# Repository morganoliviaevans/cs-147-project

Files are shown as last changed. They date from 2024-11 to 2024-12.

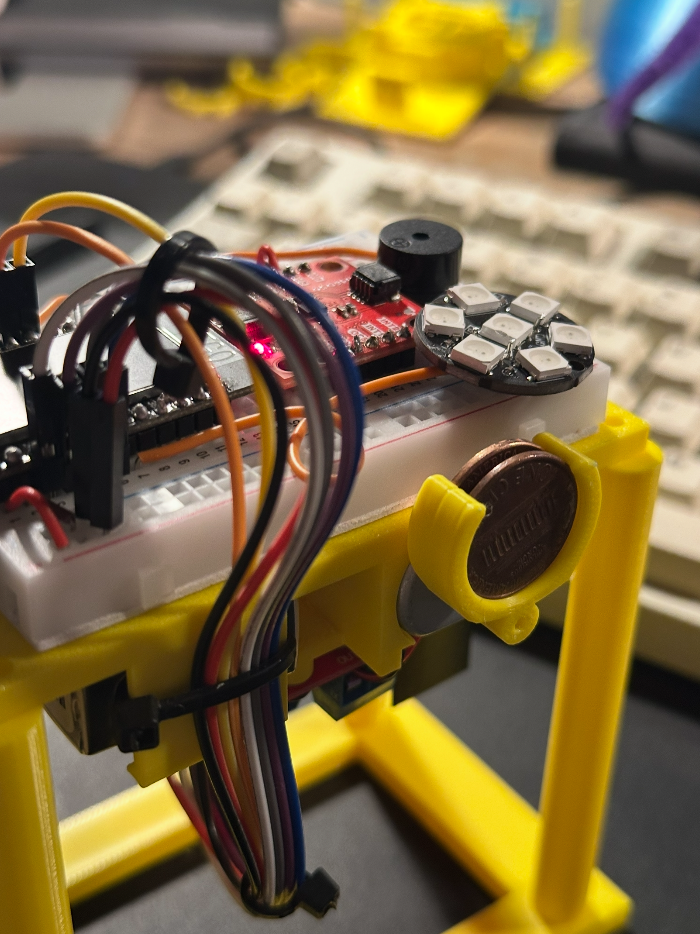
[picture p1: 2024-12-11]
images/hardware-housing1.png

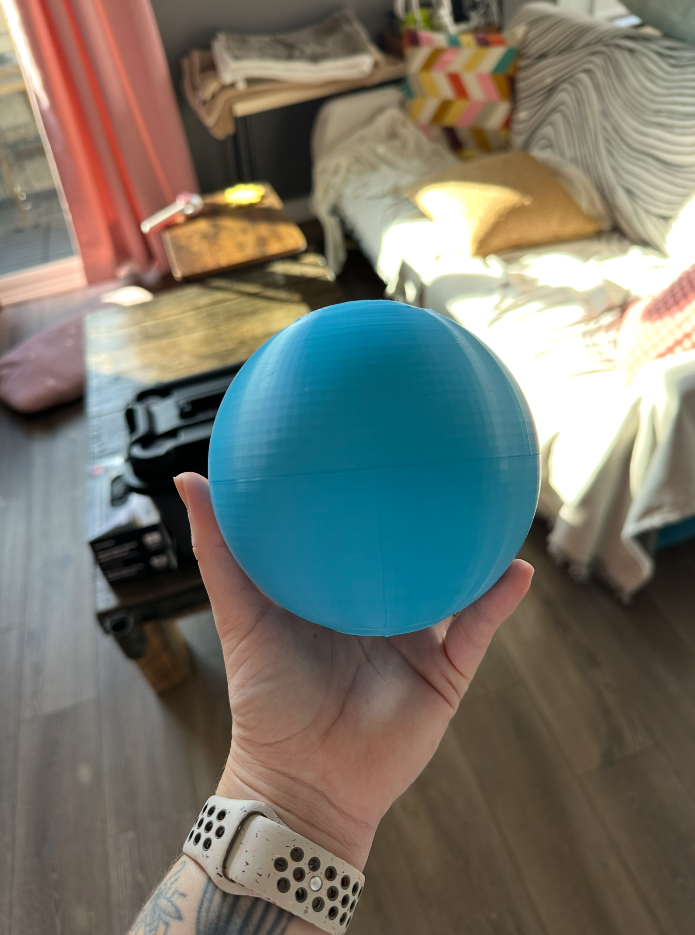
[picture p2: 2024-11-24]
images/design-prototype.png

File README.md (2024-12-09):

# Smarter Playtime: Developing a Motion-Based Motorized Cat Toy for Active Engagement

## Project Overview

This repository contains the files for **"Smarter Playtime"**, a project developed as part of **CS 147: Internet of Things (IoT) Software and Systems**. The project aims to provide active engagement for cats through a motorized toy that incorporates motion detection, customizable features, and automated play patterns to keep cats entertained.

## Team Information

- **Team Name**: Kitty Kinetics
- **Team Members**:
  - **Morgan Newton** – monewton@uci.edu
  - **Carm Hermosilla** – cyhermos@uci.edu

## Motivation

Many cat toys available today fail to keep cats consistently entertained, leading to a lack of exercise and stimulation. This can cause behavioral and health problems for pets, creating stress for both cats and their owners. Our project aims to solve this by providing a customizable, automated solution to ensure cats stay active and engaged.

## Project Goals

The project focuses on developing a motorized toy with interchangeable attachments (feathers, bells, ribbons, etc.), automated movement triggered by motion detection, visual stimulation using LEDs, and bird chirping via a buzzer. Power is supplied via rechargeable LIPO battery for convenience and long-term usability.

## Repository Structure

- **/src**: Source code for the project.
- **/docs**: Documentation, design, and architecture.
- **/images**: Photos and diagrams of the prototype and development process.

## Hardware Components

- LilyGo ESP32 microcontroller
- LED Ring
- Accelerometer
- Motor and Motor Driver
- 3D-printed spherical housing
- LIPO battery
- Toy attachments (feathers, wiggly worms, etc.)
- Buzzer

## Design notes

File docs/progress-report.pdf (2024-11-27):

COMPSCI 147: IOT SW AND SYSTEMS | PROJECT PROGRESS REPORT

## Project Title

(Try to choose a catchy title. Max 20 words).

Smarter Playtime: Developing a Motion-Based Motorized Cat Toy for Active Engagement

## Student and Team Information

Team Name: Kitty Kinetics Team # on Canvas: 2

Team member 1 (Team Lead): Newton, Morgan: 40885576: monewton@uci.edu | Newton, Morgan – 40885576

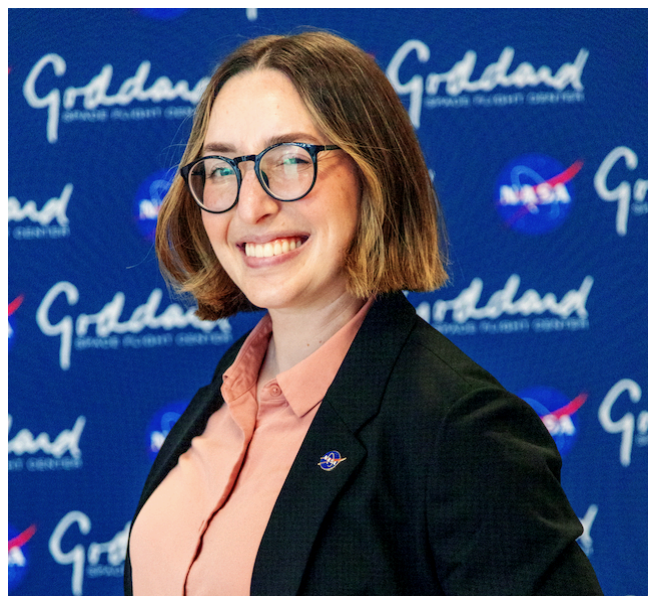
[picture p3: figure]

Team member 2: Hermosilla, Carm: 76038461: cyhermos@uci.edu | Hermosilla, Carm – 76038461

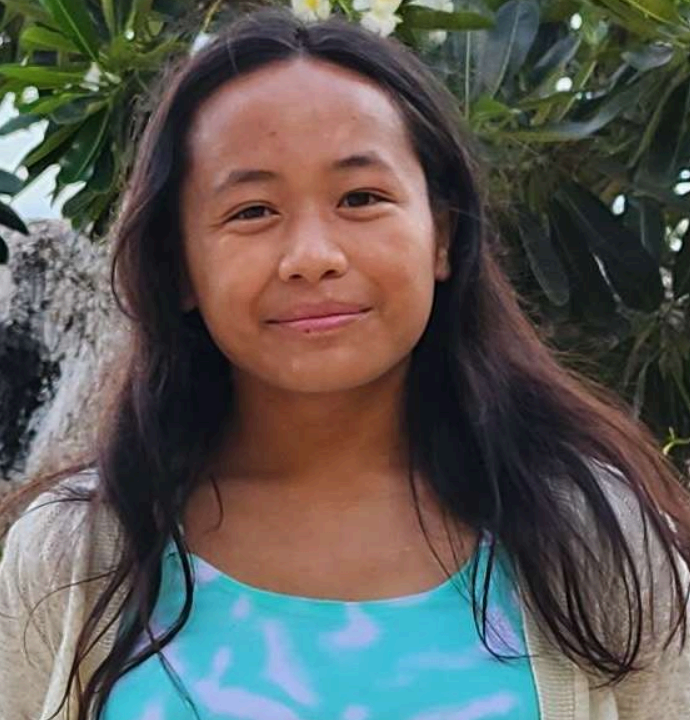
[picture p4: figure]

v.01-26032021 | Page 1

## Updated Project Approach (10 points)

(Describe how you plan to articulate and design a solution, architecture you are finally using and communication protocol (Wi-Fi, BLE, ...). Include all project milestones as well. Max 300 words).

Our project uses a motion, sound and light approach to engage cats, with an architecture based on the LilyGo ESP32 microcontroller. We decided to use an accelerometer to detect movement along the x, y, or z axes, triggering the toy when a cat interacts with it. After experimenting with proximity sensing, we opted to omit it because it is impractical for a spherical design. The toy is housed in a modified hollow sphere, allowing embedded LEDs and attachments like feathers or bells. The .stl file was downloaded for free from Thingiverse and manually adjusted per our device specifications. Power will be supplied via an external USB power bank for simplicity and ease of replacement. We realized that a shutdown mode is unnecessary as the device powers off naturally when the battery depletes. We want the cats to enjoy playing with the device for as long as possible.

## Updated Hardware Components (5 pts)

(The final list and quantity of the required components for the project)

Component | Type | Quanti ty | Ordered?
Microcontroller | LilyGo ESP32 | 1
LEDs | LEDs (https://www.amazon.com/gp/product/B0C7C9HP9R/ref=ppx_yo_dt_b_asin_title_o00_s01?ie=UTF8&th=1) | 1
Resistors | Resistors | 1-4
Accelerometer | Accelerometer (https://www.sparkfun.com/products/18020) | 1
Spherical housing | Thingiverse (https://www.thingiverse.com/thing:5828088) | 1
Motor | Motor (https://www.amazon.com/gp/product/B09FPXF1QK/ref=ppx_yo_dt_b_asin_title_o00_s00?ie=UTF8&th=1) Motor tutorial (https://www.tutorialspoint.com/arduino/arduino_dc_motor.htm) | 1
Motor driver | Motor Driver (https://www.amazon.com/gp/product/B0CR6BX5QL/ref=ppx_yo_dt_b_asin_title_o00_s01?ie=UTF8&psc=1) | 1
USB Power supply | *Need to find a small rechargeable power bank* | 1
Motor power supply | *Potentially going to use a Lipo battery* | 1
Buzzer | Buzzer/Speaker | 1
Attachments | Feathers, bells, wiggly worms | 5

## Completed Project Tasks (15 pts)

(Describe the main tasks that have been assigned and already completed. Max 250 words)

Task Completed | Team Member
Designed and printed a hollow sphere prototype from Thingiverse and tested it with the cats. They seemed to like it! | Morgan
Adjusted the housing file to add perforations for the LED lights and an embedded hook for attachments. | Morgan
Implemented sensor logic for initializations, LED flashing, bird chirps, and motion detection using an accelerometer. | Morgan
Ordered the rest of our parts: LED, motor, motor driver, device attachments | Morgan

## Challenges and Roadblocks (10 pts)

(Describe the challenges that you have faced or are facing so far and how you plan to solve them. Max 300 words)

Balancing the scope and timeline of the project has been a challenge, requiring us to simplify certain features, such as omitting battery life tracking, which was deemed unnecessary. I think we got a bit too ambitious! We also faced hardware compatibility issues, as initial microcontroller libraries caused delays, but these were resolved by switching to more suitable options. Fine-tuning the accelerometer’s logic has been another focus, ensuring it responds accurately to motion while avoiding false triggers. To streamline power management, we are opting for an external USB power bank, eliminating the need for a shutdown mode, which significantly simplifies the design. Additionally, proximity sensing was excluded from the project due to the spherical housing design, which made it impractical to direct sensors effectively. For example, the sensor might be pointed down at the ground, which would pose issues with reading. Instead, we will rely on accelerometer-based motion detection to activate the toy. Additionally, programming each peripheral to run concurrently proved to be much more difficult than originally planned.

## Pending Tasks (10 pts)

(Describe the main tasks that you still need to complete. Max 250 words)

Task | Team Member
Adding AWS data analytics tracking for play time | Morgan
Analyzing and summarizing data analytics | Carm
Select and test an external USB power solution | Morgan
Hardware Build | Carm
Testing the device | Morgan
Logic adjustments | Morgan
Demo Video | Carm + Morgan
Final Report | Carm + Morgan

## Weak Points and Future Work (15 pts)

(Mention at least two points of your project that have room for improvement. These points can be additions to the existing project setup (components) or improvement of the current implementation. Max 200 words)

For future iterations, integrating a power source that allows battery tracking would enhance usability by providing real-time feedback on battery levels. This would be helpful in analyzing battery life to compare different, better options, if necessary. Additionally, modifying the spherical housing to include a weighted base could improve stability and create opportunities for incorporating proximity sensing functionality, which was not feasible in the current design. Another area for improvement could involve refining the accelerometer’s sensitivity and responsiveness, enabling more precise motion detection. Adding customizable play patterns, such as programmed light and sound sequences, could further enhance the toy’s engagement factor. Adjusting peripheral timing was also fairly difficult. Future implementations would hopefully focus on creating logic to allow parallel peripheral execution. Lastly, if we hypothetically were interested in bringing the device to market, exploring durable materials for the housing could extend the product’s lifespan, as well as sourcing smaller hardware components.

## Demo Video (15 pts)

Please include a link to a demo video showing the initial setup, the components and functionality of your IoT system (5 min max). If you cannot provide a video yet, please explain the reasons. Max 150 words).

Our demo video showcases Charlie (Morgan’s cat) playing with the 3D-printed ball prototype, made of PLA. The second clip demonstrates the sleep state to play state transition. If the toy is moved, the play state is activated. The third video showcases the serial monitor output, displaying the toy’s state, its position via x and y coordinates, and magnitude to elucidate how much the toy has moved. The play state will move each motor randomly, flash the led, and chirping noises. If the cat is not interested momentarily, the hunting state is activated which turns on the led and chirping noises. If the cat is completely uninterested, the device shifts to a sleep state to consume less battery. This output will be sent to the AWS database to monitor the current session’s play duration and frequency between interactions. State timing changes have small delays for demonstration purposes, but will be readjusted after testing.

Watch Demo Video Here (https://drive.google.com/file/d/1DOTv-FsJgOIQEgGuwi69TlJ3ngiTCjjo/view?usp=sharing)

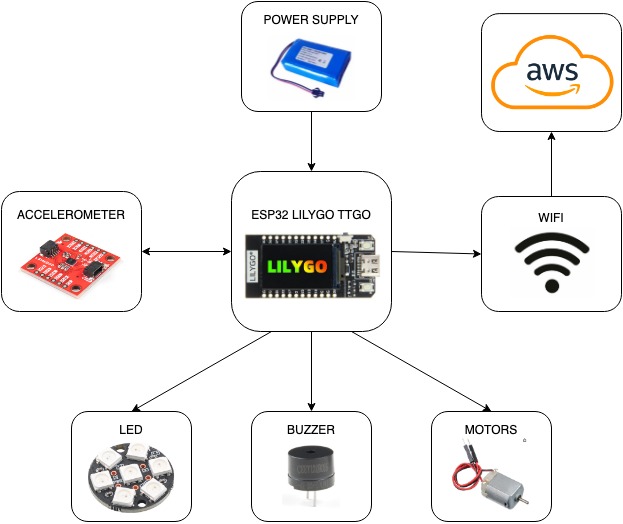
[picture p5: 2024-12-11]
images/architecture-diagram.jpg

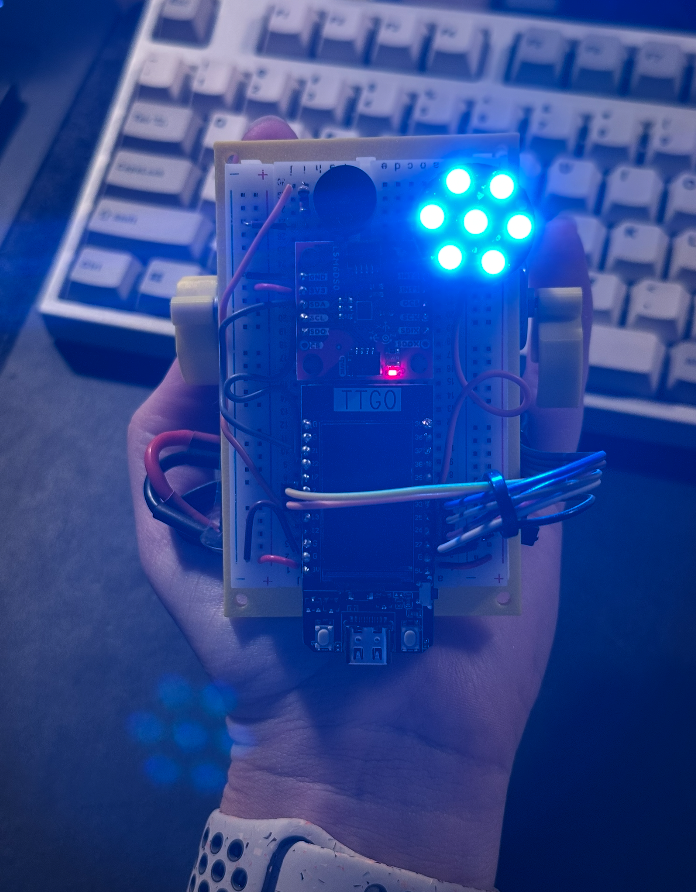
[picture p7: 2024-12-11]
images/hardware-housing6.png

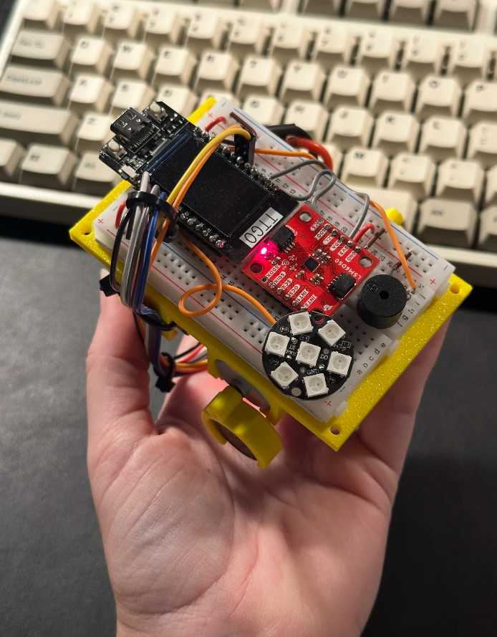
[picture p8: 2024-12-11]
images/hardware-housing2.png

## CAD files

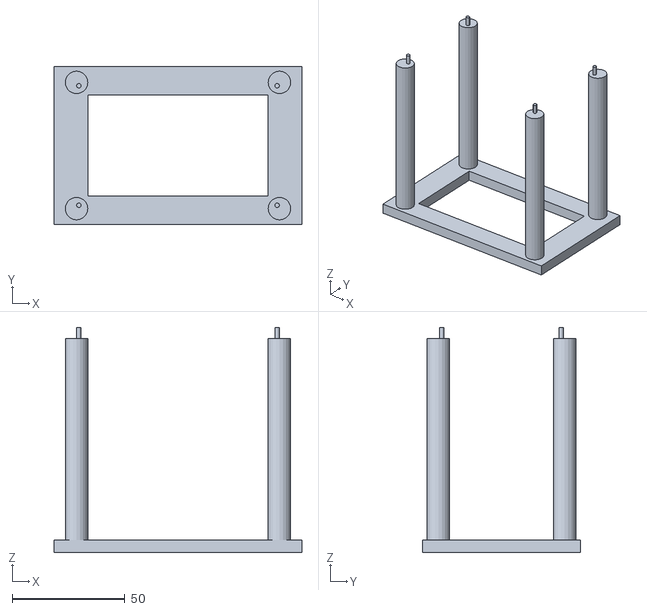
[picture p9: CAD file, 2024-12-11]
3d-housing/final/final-device-plate-stand.stl
110.0 x 70.0 x 100.0

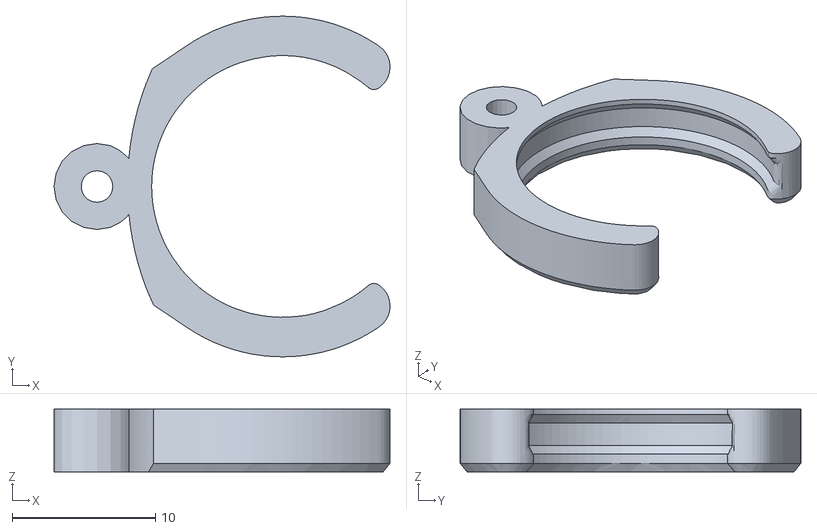
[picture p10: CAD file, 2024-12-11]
3d-housing/penny-weight-single.stl
23.4 x 23.8 x 4.39

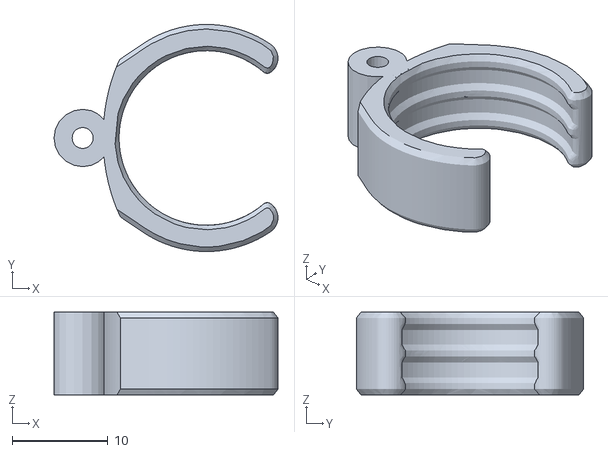
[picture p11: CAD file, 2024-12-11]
3d-housing/final/final-penny-weight-double.stl
23.4 x 23.8 x 8.67

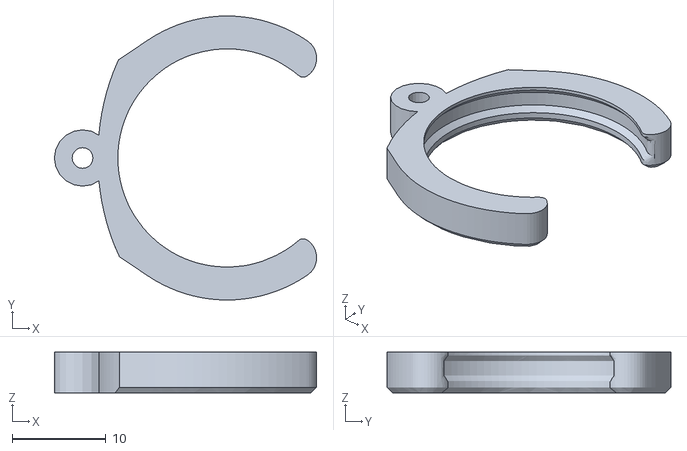
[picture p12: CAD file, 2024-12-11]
3d-housing/quarter-weight-single.stl
27.9 x 30.2 x 4.34

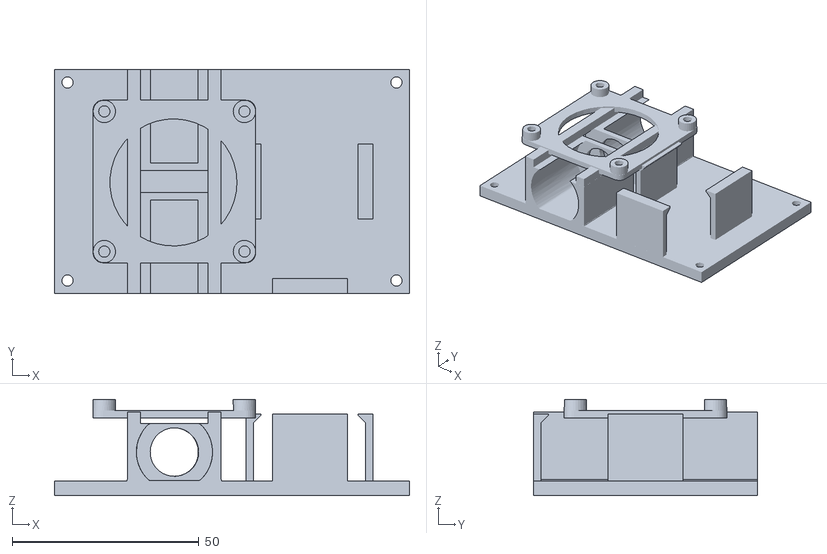
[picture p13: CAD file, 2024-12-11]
3d-housing/final/final-motor-hardware-plate.stl
95.0 x 60.0 x 25.8

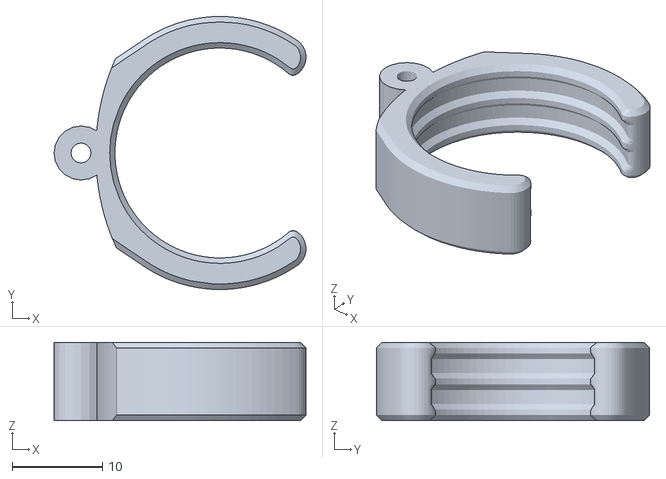
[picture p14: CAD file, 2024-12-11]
3d-housing/quarter-weight-double.stl
27.9 x 30.3 x 8.67

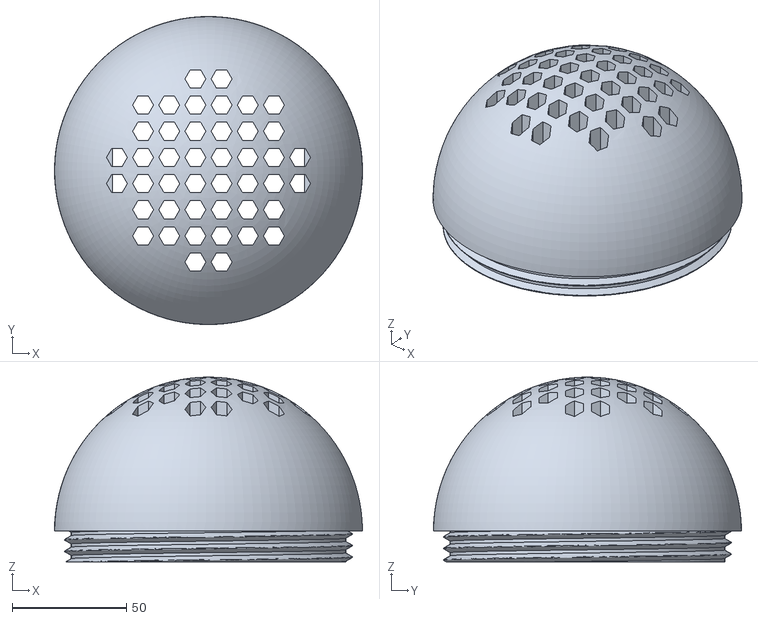
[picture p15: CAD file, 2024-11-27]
3d-housing/final/final-sphere-male-perforated.stl
135.0 x 135.0 x 81.0

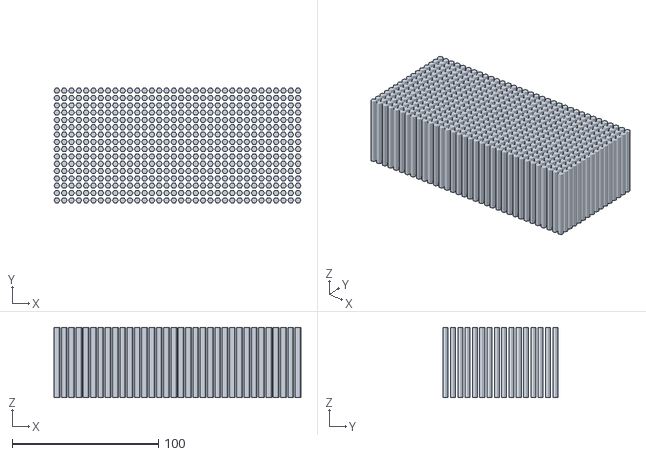
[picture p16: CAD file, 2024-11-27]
3d-housing/perforation-raw.stl
169.0 x 78.5 x 48.0

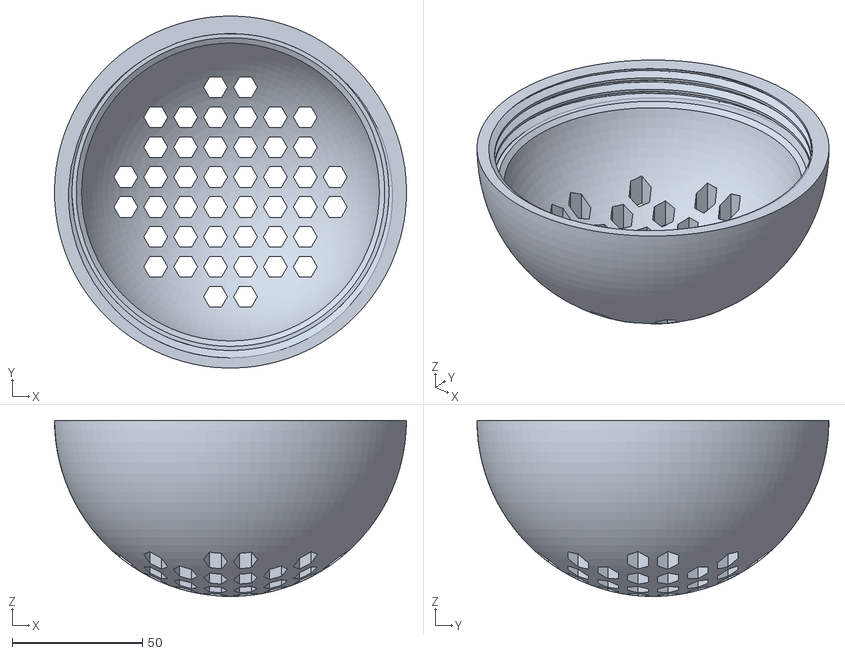
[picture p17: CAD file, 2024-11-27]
3d-housing/final/final-sphere-female-perforated.stl
135.0 x 135.0 x 67.5

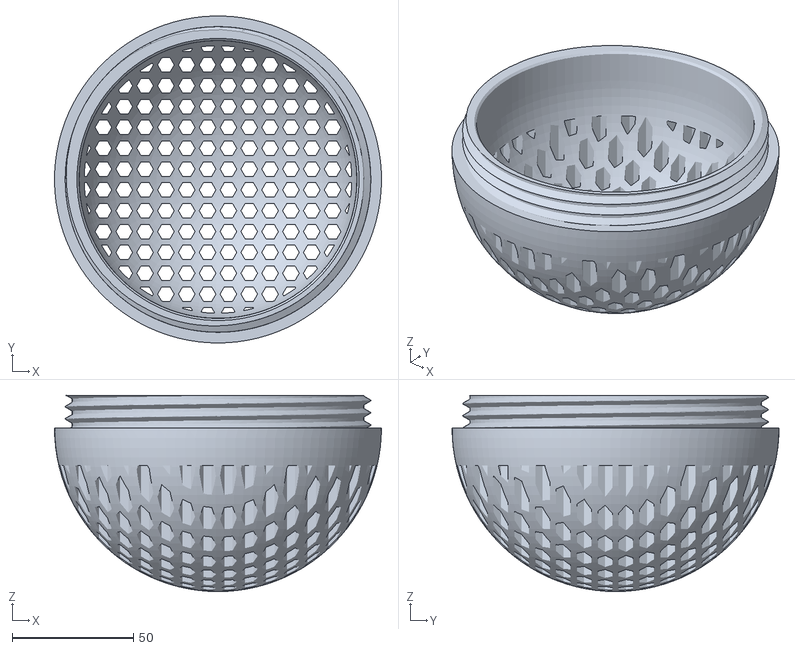
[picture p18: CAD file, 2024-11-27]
3d-housing/male-sphere-perforated.stl
135.0 x 135.0 x 81.0

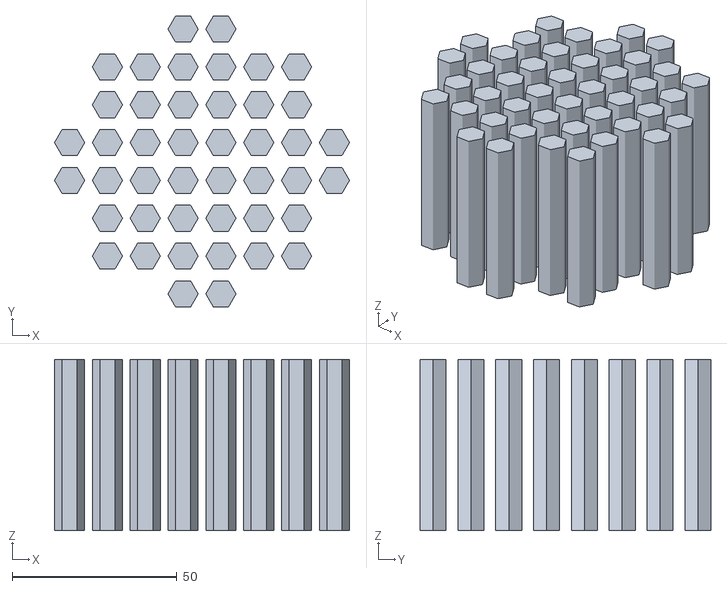
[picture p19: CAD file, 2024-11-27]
3d-housing/perforation-scaled.stl
89.5 x 88.2 x 52.0

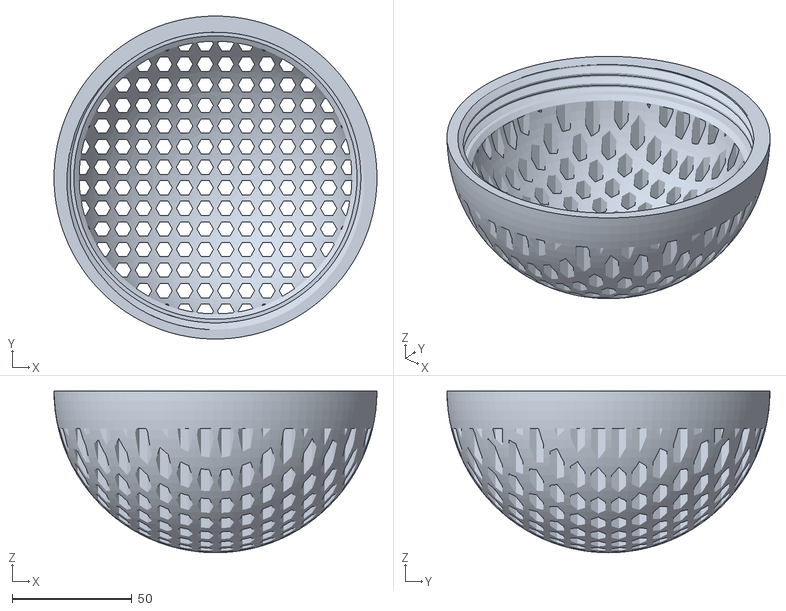
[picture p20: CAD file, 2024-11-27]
3d-housing/female-sphere-perforated.stl
135.0 x 135.0 x 67.5

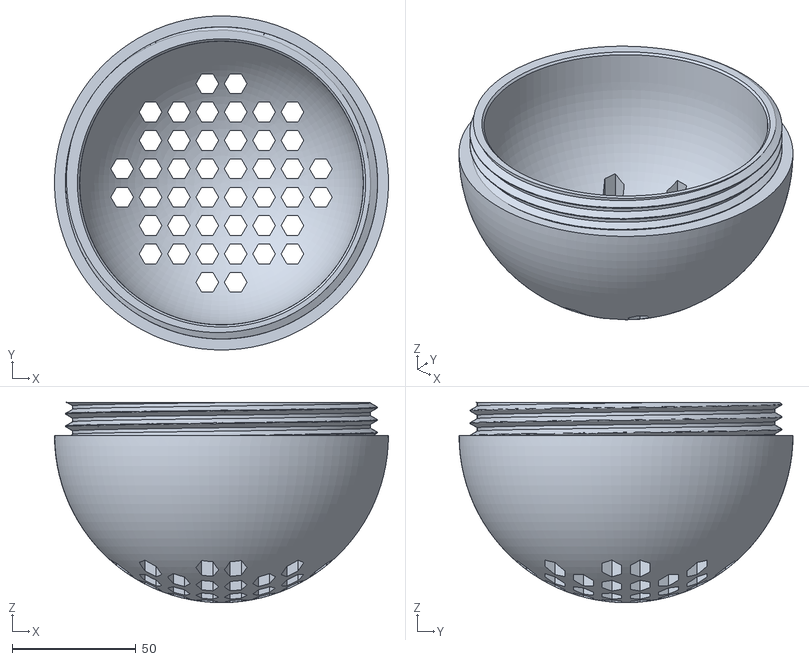
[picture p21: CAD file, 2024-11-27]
3d-housing/male-perforated-no-mount.stl
135.0 x 135.0 x 81.0

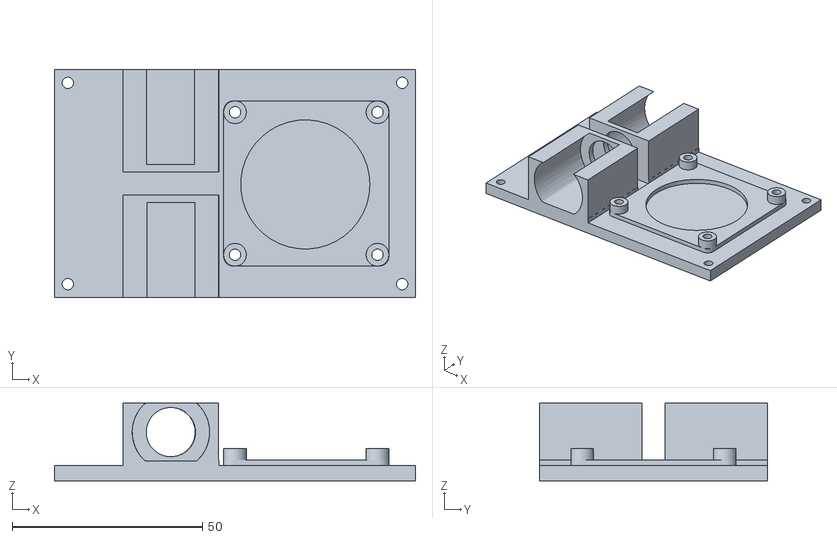
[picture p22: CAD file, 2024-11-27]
3d-housing/motor-hardware-plate.stl
95.0 x 60.0 x 20.5

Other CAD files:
3d-housing/298L-holder.stl
3d-housing/sphere-male-raw.stl
3d-housing/130-holder.stl
3d-housing/device-plate-stand.stl
3d-housing/sphere-female-raw.stl

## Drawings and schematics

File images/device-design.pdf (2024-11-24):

e

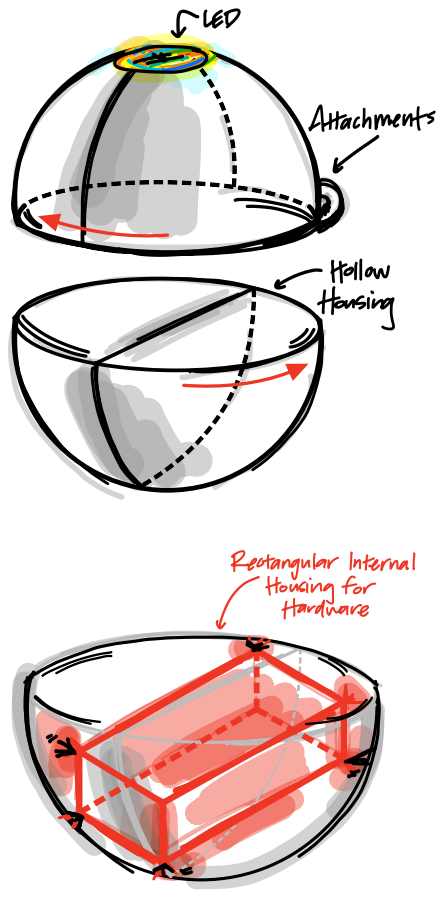
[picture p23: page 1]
iiiii; RectangularInternal Husinature; GRIEF

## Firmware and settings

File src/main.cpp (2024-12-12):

/*
CS 147: IoT Software and Systems
Course Project - Motorized Cat Toy
Team Member 1: Morgan Newton
Team Member 2: Carm Hermosilla
Due Date: 12-13-2024
*/

/*
Project Breakdown:

Initialization and Setup
    1. Initialize the microcontroller and set up peripherals: LEDs, motor, accelerometer, buzzer
    2. Define all GPIO pins for the connected components
    3. Set default states for LEDs (off), motor (idle), and buzzer (off)

State 1: Play State
    1. Detect accelerometer activity
    2. Did our x-axis, y-axis, or z-axis move? Activate the toy!
    3. Adjust LED flashing rate to conserve battery (flash once every 30 seconds)
    4. Continue randomizing motor speed and direction
    5. Continue periodic bird noises
    6. If the toy is idle for 1 minute, switch to hunting state
    7. Track play time within play state -- are we playing? Add this play time to our stored play time variable
    8. Send play state analytics to the Cloud

State 2: Hunting State
    1. Check accelerometer data for inactivity for 1 minute
    2. Trigger attention-grabbing behavior -- LED flashing, bird noises
    3. Once cat moves the ball, we switch back to play state
    4. If the cat does not move the ball after 2 minutes, go into sleep state

State 3: Sleep State
    1. Turn off LEDs and turn off the motor to conserve battery
    2. Keep accelerometer active to detect the cat’s return
    3. Re-enter play state upon detecting motion
    4. Track sleep time within sleep state -- are we sleeping? Add this sleep time to our stored sleep time variable
    5. Send sleep state analytics to the Cloud
*/

// ----------------------- BASIC LIBRARIES -----------------------------
#include <SPI.h>
#include <Wire.h>
#include <stdio.h>
#include <Arduino.h>
// ----------------------- CLOUD ---------------------------------------
#include "nvs.h"
#include "esp_wifi.h"
#include "nvs_flash.h"
#include "esp_system.h"
#include <HttpClient.h>
#include "freertos/task.h"
#include "freertos/FreeRTOS.h"
#include <WiFi.h>

// ----------------------- ACCELEROMETER -------------------------------
#include "SparkFunLSM6DSO.h"
// ----------------------- LED -----------------------------------------
#include <Adafruit_NeoPixel.h>

// ----------------------- VARIABLE DECLARATIONS -----------------------

#define BUZZER_PIN 12
#define LED_PIN 32
#define NUM_LEDS 7

// Motor pins
#define ENA 2           // PWM pin for Motor 1 (speed control)
#define ENB 15          // PWM pin for Motor 2 (speed control)
#define IN1 27          // Motor 1 Direction
#define IN2 26          // Motor 1 Direction
#define IN3 25          // Motor 2 Direction
#define IN4 33          // Motor 2 Direction

// Network
char ssid[50];          // SSID
char pass[50];          // Password

// Motor PWM Configurations (speed control)
int freq = 5000;        // PWM frequency
int resolution = 8;     // 8-bit resolution (0-255 for duty cycle)
int pwmChannelA = 0;    // PWM Channel for Motor 1
int pwmChannelB = 1;    // PWM Channel for Motor 2

unsigned long stateStartTime = millis();
unsigned long playTime = 0; // For tracking PLAY state total time
unsigned long sleepTime = 0; // For tracking SLEEP state total time
unsigned long playStartTime = 0;
unsigned long sleepStartTime = 0;

// NeoPixel strip object
Adafruit_NeoPixel strip(NUM_LEDS, LED_PIN, NEO_GRB + NEO_KHZ800);

// Device States
enum DeviceState { PLAY, HUNTING, SLEEP };
DeviceState currentState = PLAY;

// Accelerometer object
LSM6DSO myIMU;
// Accelerometer variables
float x_axis, y_axis;
float magnitude;

// // AWS object
// AWS_IOT aws;

// ----------------------- FUNCTION DECLARATIONS -----------------------

void chirp();
void off_led();
void slow_led();
void play_mode();
void flash_led();
void sleep_mode();
void nvs_access();
void stop_motors();
void hunting_mode();
void random_colors();
void reset_AWS_data();
void run_motors(int speed);
void send_time_AWS(unsigned long playTime, unsigned long sleepTime);
void ramp_down_motor_speed(int initialSpeed, int targetSpeed, int rampTime);

// ----------------------- SETUP ---------------------------------------

void setup() {
    // ------------------- SERIAL COMMUNICATION ------------------------
    Serial.begin(9600);
    delay(500);
    // Initial state
    Serial.println("Our initial state is PLAY!"); 
    // Initialize I2C  
    Wire.begin();
    delay(500); 

    // ------------------- WIFI INITIALIZATION -------------------------
    // Get Wifi creds for non-volatile storage
    nvs_access(); 
    // Connect to Wi-Fi
    Serial.print("Connecting to ");
    Serial.println(ssid);
    WiFi.begin(ssid, pass);
    // While wifi not connected...
    while (WiFi.status() != WL_CONNECTED) {
        delay(500);
        Serial.println(".");
    }
    Serial.println("Connected to WiFi. Have fun!");
    Serial.println("IP address: ");
    Serial.println(WiFi.localIP());
    Serial.println("MAC address: ");
    Serial.println(WiFi.macAddress());

    // ------------------- AWS INTITALIZATION --------------------------
    //aws.begin();
    send_time_AWS(playTime, sleepTime);
    playStartTime = millis();

    // ------------------- ACCELEROMETER INTITALIZATION ----------------

    // Initialize accelerometer
    if (myIMU.begin()) {
        Serial.println("Ready.");
    } else { 
        Serial.println("Could not connect to IMU.");
    }
    // Apply a set of default configuration settings to the accelerometer sensor
    myIMU.initialize(BASIC_SETTINGS);

    // ------------------- LED / BUZZER / MOTOR INTITALIZATIONS --------

    pinMode(LED_PIN, OUTPUT);
    pinMode(BUZZER_PIN, OUTPUT);

    // Initialize LED
    strip.begin();
    // Initialize our color to off
    strip.show();  

    // Initialize motor
    // Set direction pins as outputs
    pinMode(IN1, OUTPUT);
    pinMode(IN2, OUTPUT);
    pinMode(IN3, OUTPUT);
    pinMode(IN4, OUTPUT);

    // Start the motor driver in a disabled state
    digitalWrite(IN1, LOW);
    digitalWrite(IN2, LOW);
    digitalWrite(IN3, LOW);
    digitalWrite(IN4, LOW);

    // Configure PWM channels
    ledcSetup(pwmChannelA, freq, resolution);
    ledcSetup(pwmChannelB, freq, resolution);

    // Attach PWM channels to GPIO pins
    ledcAttachPin(ENA, pwmChannelA);
    ledcAttachPin(ENB, pwmChannelB);

    // Set motor speed to 0
    ledcWrite(pwmChannelA, 0);
    ledcWrite(pwmChannelB, 0);

    // After device is turned on and initialized, we delay for 30 seconds to screw the ball back together and put it down for play
    delay(30000);
}

// ----------------------- LOOP ----------------------------------------

void loop() {

    // Test command via serial monitor to reset AWS data for testing
    if (Serial.available() > 0) {
        char command = Serial.read();
        if (command == 'r') {  // 'r' for reset
            reset_AWS_data();
        }
    }

    unsigned long currentPlayTime = 0;

    // Update accelerometer data every loop
    x_axis = myIMU.readFloatAccelX();
    y_axis = myIMU.readFloatAccelY();

    // Print values for debugging
    Serial.print("x_axis: "); 
    Serial.println(x_axis);
    Serial.print("y_axis: "); 
    Serial.println(y_axis);
    Serial.print("Magnitude: "); 
    Serial.println(magnitude);
    Serial.println();

    switch (currentState) {

        case PLAY:
            // Debugging
            Serial.println("State: PLAY");
            Serial.println();

            // Track the current play time session
            playTime += millis() - playStartTime;
            // Reset play timer
            playStartTime = millis();                               

            // Go into play mode
            play_mode();

            // Send play time to AWS 
            send_time_AWS(playTime, sleepTime);

            // Calculate motion magnitude
            magnitude = sqrt(x_axis * x_axis + y_axis * y_axis);

            // If motion is not detected
            if (magnitude < 0.5) {
                unsigned long elapsed = millis() - stateStartTime;
                // And if it has been more than 30 seconds
                if (millis() - stateStartTime > 30000) { 
                    // Switch to hunting state
                    currentState = HUNTING;
                    // Reset state timer
                    stateStartTime = millis();
                }
            }
            break;

        case HUNTING:
            // Debugging
            Serial.println("State: HUNTING");
            Serial.println();

            // Track the current play time session
            playTime += millis() - playStartTime;
            // Reset play timer
            playStartTime = millis();        

            // Go into hunting mode
            hunting_mode();      

            // Send play time to AWS    
            send_time_AWS(playTime, sleepTime);    

            // Calculate motion magnitude
            magnitude = sqrt(x_axis * x_axis + y_axis * y_axis);

            // If motion is detected
            if (magnitude > 0.5) {
                // Switch to play state
                currentState = PLAY;
                // Reset state timer
                stateStartTime = millis();
            } 
            // If it has been more than 1 minute
            if (millis() - stateStartTime > 60000) {
                // Switch to sleep state
                currentState = SLEEP;
                // Reset state timer
                stateStartTime = millis();
            }
            break;

        case SLEEP:
            // Debugging
            Serial.println("State: SLEEP");
            Serial.println();

            // Go into sleep mode
            sleep_mode();

            // Prevent carryover        
            playStartTime = millis();                               
            // Track the current sleep time session
            sleepTime += millis() - sleepStartTime;                 
            // Reset sleep timer
            sleepStartTime = millis();                              
            // Send play and sleep time to AWS
            send_time_AWS(playTime, sleepTime);

            // Calculate motion magnitude
            magnitude = sqrt(x_axis * x_axis + y_axis * y_axis);

            // If motion is detected
            if (magnitude > 0.5) { 
                // Switch to play state    
                currentState = PLAY;
                // Reset state timer
                stateStartTime = millis();                          
            }
            break;
    }
}

// ----------------------- FUNCTION DEFINTIONS -------------------------

void random_colors() {
    /*
    Structure of uint32_t in NeoPixel:
	Bits 31–24: Reserved
	Bits 23–16: Red (0–255)
	Bits 15–8:  Green (0–255)
	Bits 7–0:   Blue (0–255)
    strip.Color(red, green, blue)
    */

    // Create a beautiful array of colors using RGB values
    uint32_t colors[] = {
        strip.Color(255, 0, 0),     // Red
        strip.Color(255, 165, 0),   // Orange
        strip.Color(255, 215, 0),   // Gold
        strip.Color(255, 255, 0),   // Yellow
        strip.Color(0, 255, 0),     // Green
        strip.Color(0, 128, 128),   // Teal
        strip.Color(0, 0, 255),     // Blue
        strip.Color(75, 0, 130),    // Indigo
        strip.Color(148, 0, 211),   // Violet
        strip.Color(255, 192, 203)  // Pink
    };

    for (int i = 0; i < 4; i++) {
        // Cycle through each color in our array
        for (int colorIndex = 0; colorIndex < sizeof(colors) / sizeof(colors[0]); colorIndex++) {
            // Set all LEDs to the same color
            for (int i = 0; i < NUM_LEDS; i++) {
                strip.setPixelColor(i, colors[colorIndex]);
            }
            // Display the color on the LED
            strip.show();
            // Hold each color for 0.200 second
            delay(200); 
        }
        // Turn off the LED
        off_led();
    }
}

void off_led() {
    // Shut off the LED by setting it to black
    for (int i = 0; i < NUM_LEDS; i++) {
        strip.setPixelColor(i, strip.Color(0, 0, 0));
    }
    // Display "black" e.g. show that it is shut off
    strip.show();
}

void slow_led() {
    // Turn on LED
    digitalWrite(LED_PIN, HIGH);
    // Flash LED
    random_colors();
    // Delay for 2 seconds
    delay(2000);
}

void flash_led() {
    // Turn on LED
    digitalWrite(LED_PIN, HIGH);
    // Flash LED
    random_colors();
}

void stop_motors() {
    // Stop Motor 1
    digitalWrite(IN1, LOW);
    digitalWrite(IN2, LOW);
    ledcWrite(pwmChannelA, 0);

    // Stop Motor 2
    digitalWrite(IN3, LOW);
    digitalWrite(IN4, LOW);
    ledcWrite(pwmChannelB, 0);
}

void run_motors(int targetSpeed) {                                            
    // Define ramp parameters
    int initialSpeed = 150;  // Starting speed for ramp-up
    int rampTime = 1000;    // Time to ramp down (in milliseconds)

    // Move motor 1 forward
    Serial.println("Motor 1 Forward...");
    digitalWrite(IN1, HIGH);
    digitalWrite(IN2, LOW);
    // Move motor 2 backward
    Serial.println("Motor 2 Backward...");
    digitalWrite(IN3, LOW);   
    digitalWrite(IN4, HIGH);

    // Ramp down motor speed forward
    ramp_down_motor_speed(initialSpeed, targetSpeed, rampTime);

    // Keep moving at the target speed for a random duration
    delay(random(2000, 6000));

    // Pause motors for a random duration (2-6 seconds)
    stop_motors();
    Serial.println("Stopping Motors...");
    delay(random(2000, 6000));

    // Move motor 1 forward
    Serial.println("Motor 1 Forward...");
    digitalWrite(IN1, HIGH);
    digitalWrite(IN2, LOW);
    // Move motor 2 backward
    Serial.println("Motor 2 Backward...");
    digitalWrite(IN3, LOW);   
    digitalWrite(IN4, HIGH);

    // Ramp down motor speed backward
    ramp_down_motor_speed(initialSpeed, targetSpeed, rampTime);

    // Keep moving at the target speed for a random duration
    delay(random(1000, 3000));

    // Pause motors
    stop_motors();
}


void ramp_down_motor_speed(int initialSpeed, int targetSpeed, int rampTime) {
    int stepDelay = 100; // Time delay between steps (in milliseconds)
    int steps = rampTime / stepDelay; // Number of steps to reach target speed
    int speedStep = (initialSpeed - targetSpeed) / steps; // Speed decrement per step

    // Start motor at the initial speed
    ledcWrite(pwmChannelA, initialSpeed);
    ledcWrite(pwmChannelB, initialSpeed);

    for (int i = 0; i < steps; i++) {
        int currentSpeed = initialSpeed - (speedStep * i);
        if (currentSpeed < targetSpeed) break;

        // Update motor speed
        ledcWrite(pwmChannelA, currentSpeed);
        ledcWrite(pwmChannelB, currentSpeed);

        // Wait before adjusting speed further
        delay(stepDelay);
    }

    // Final adjustment to target speed
    ledcWrite(pwmChannelA, targetSpeed);
    ledcWrite(pwmChannelB, targetSpeed);
}

void play_mode() {
        Serial.println("Play Mode...");
        delay(1000);
        // Target Speed
        int targetSpeed = (100);
        run_motors(targetSpeed);
        // Chirp!
        chirp();
        // Flash the slower LED
        slow_led();
}

// Chirp and flash to get the cat's attention
void hunting_mode() {
        Serial.println("Hunting Mode...");
        delay(1000);
        // Random chance to chirp first or flash LED first
        if (random(0, 2) == 0) {
            chirp();
            flash_led();
        } else {
            flash_led();  
            chirp();
        }
}

void sleep_mode() {
    Serial.println("Sleep Mode...");
    // Turn off LED
    off_led();
    // Stop motors
    stop_motors();
}

void chirp() {
    // High-to-low chirps
    int high_to_low_chirps = 5;
    while (high_to_low_chirps > 0) {
        for (int pitch = 300; pitch > 0; pitch--) {
            digitalWrite(BUZZER_PIN, HIGH);
            delayMicroseconds(pitch);
            digitalWrite(BUZZER_PIN, LOW);
            delayMicroseconds(pitch);
        }
        delay(100);
        high_to_low_chirps--;
    }

    // Low-to-high chirps
    int low_to_high_chirps = 10;
    while (low_to_high_chirps > 0) {
        for (int pitch = 0; pitch < 300; pitch++) {
            digitalWrite(BUZZER_PIN, HIGH);
            delayMicroseconds(pitch);
            digitalWrite(BUZZER_PIN, LOW);
            delayMicroseconds(pitch);
        }
        delay(100);
        low_to_high_chirps--;
    }

    // Final high-to-low chirp
    for (int pitch = 300; pitch > 0; pitch--) {
        digitalWrite(BUZZER_PIN, HIGH);
        delayMicroseconds(pitch);
        digitalWrite(BUZZER_PIN, LOW);
        delayMicroseconds(pitch);
    }
    delay(400);

    // High-to-low chirps with a longer delay
    high_to_low_chirps = 5;
    while (high_to_low_chirps > 0) {
        for (int pitch = 300; pitch > 0; pitch--) {
            digitalWrite(BUZZER_PIN, HIGH);
            delayMicroseconds(pitch);
            digitalWrite(BUZZER_PIN, LOW);
            delayMicroseconds(pitch);
        }
        delay(400);
        high_to_low_chirps--;
    }

    // Low-to-high chirps
    low_to_high_chirps = 10;
    while (low_to_high_chirps > 0) {
        for (int pitch = 0; pitch < 300; pitch++) {
            digitalWrite(BUZZER_PIN, HIGH);
            delayMicroseconds(pitch);
            digitalWrite(BUZZER_PIN, LOW);
            delayMicroseconds(pitch);
        }
        delay(100);
        low_to_high_chirps--;
    }

    // Final high-to-low chirp
    for (int pitch = 300; pitch > 0; pitch--) {
        digitalWrite(BUZZER_PIN, HIGH);
        delayMicroseconds(pitch);
        digitalWrite(BUZZER_PIN, LOW);
        delayMicroseconds(pitch);
    }
}

// ----------------------- Data Analytics -----------------------

// Non-volatile storage: Keeps data even if toy runs out of battery
void nvs_access() {

    // Initialize NVS
    esp_err_t err = nvs_flash_init();
    if (err == ESP_ERR_NVS_NO_FREE_PAGES || err == ESP_ERR_NVS_NEW_VERSION_FOUND) {
        ESP_ERROR_CHECK(nvs_flash_erase());
        err = nvs_flash_init();
    }
    ESP_ERROR_CHECK(err);

    // Open
    Serial.printf("\n");
    Serial.printf("Opening Non-Volatile Storage (NVS) handle... ");
    nvs_handle_t my_handle;
    err = nvs_open("storage", NVS_READWRITE, &my_handle);

    if (err != ESP_OK) {
        Serial.printf("Error (%s) opening NVS handle!\n", esp_err_to_name(err));
    } else {
        Serial.printf("Done\n");
        Serial.printf("Retrieving SSID/PASSWORD\n");

        size_t ssid_len;
        size_t pass_len;

        err = nvs_get_str(my_handle, "ssid", ssid, &ssid_len);
        err |= nvs_get_str(my_handle, "pass", pass, &pass_len);

        switch (err) {
            case ESP_OK:
                Serial.printf("Done\n");
                break;
            case ESP_ERR_NVS_NOT_FOUND:
                Serial.printf("The value is not initialized yet!\n");
                break;
            default:
                Serial.printf("Error (%s) reading!\n", esp_err_to_name(err));
        }
    }
    // Close
    nvs_close(my_handle);
}

void send_time_AWS(unsigned long playTime, unsigned long sleepTime) {
    Serial.print("Sending play time to AWS: ");
    Serial.println(playTime);
    Serial.print("Sending sleep time to AWS: ");
    Serial.println(sleepTime);

    WiFiClient client; 
    // Send POST request
    if (client.connect("3.85.208.114", 5000)) {
        String payload = "{\"test\": true, \"playTime\": " + String(playTime) + ", \"sleepTime\": " + String(sleepTime) + "}";
        //String payload = "{\"playTime\": " + String(playTime) + ", \"sleepTime\": " + String(sleepTime) + "}";

        client.println("POST /send-time HTTP/1.1");
        client.println("Host: 3.85.208.114");
        client.println("Content-Type: application/json");
        client.print("Content-Length: ");
        client.println(payload.length());
        client.println();
        client.print(payload);

        // Read response from client (the debugger)
        String response = client.readString();
        Serial.println("Response: " + response);

        client.stop();
    } else {
        Serial.println("Failed to connect to the server.");
    }
}

// Manually reset AWS data for testing
void reset_AWS_data() {
    playTime = 0;
    sleepTime = 0;
    playStartTime = millis(); // Reset play timer
    sleepStartTime = millis(); // Reset sleep timer
    Serial.println("Play and sleep times reset for testing.");
}

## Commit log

2024-11-24 Logic implemented, pending testing
    Added device design and photo of housing prototype
2024-11-27 Added several updates to logic:
    - Reduced and improved state logic significantly
    - Implemented accelerometer-based state transitions using motion magnitude
    - Fixed and optimized LED functionality to utilize all 7 LEDs, cycle colors, and shut off
    - Debugged and streamlined motor control
    - Tested buzzer chirping functionality after hardware issue with pin
    - Adjusted serial monitor output for state debugging and accelerometer readings
    - Added comments for Cloud functionality
    [main.cpp]
2024-11-27 Added .stl files and screenshots for housing design
    [130-holder.stl, 298L-holder.stl, female-sphere-perforated.stl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]
2024-12-10 Added accelerometer datasheet
2024-12-10 Finalizing Cloud implementation and motor improvements • Cloud Implementation: • Completed integration for sending playTime and sleepTime to AWS • Verified server communication and added error handli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
    • Motor Improvements:
    • Refined motor ramping logic for smoother transitions and reduced hardware strain
    • Added wobbling motion with alternating motor directions for more engaging behavior
    • Going to continue some adjustments and complete later today
    [main.cpp]
2024-12-11 Added final 3D housing .stl's and device images
    [device-plate-stand.stl, final-device-plate-stand.stl, final-motor-hardware-plate.stl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]
